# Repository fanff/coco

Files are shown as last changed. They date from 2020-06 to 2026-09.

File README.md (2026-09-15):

# Coco Walker

Software for **Coco**, a small **bipedal** walking robot. Coco has **two legs** and is driven by **four hobby servos**—a foot and a hip on each side (see `iv.py`). The repo runs on a **Raspberry Pi Zero W** with **pigpio** driving servo PWM on GPIO, and includes tools to design gaits, run them live, and control the robot from a browser.

Python dependencies are managed with **[uv](https://docs.astral.sh/uv/)** (`pyproject.toml` + `uv.lock`).

## Hardware

- **Computer**: Raspberry Pi Zero W
- **Biped**: two legs, four degrees of freedom total
- **4× MG90S servos** (2 per leg): foot + hip on left and right (mapping in `iv.py`)
- **Servo control**: [pigpio](https://abyz.me.uk/rpi/pigpio/) on four GPIO lines (`servoGpios` in `iv.py`); legacy PCA9685 ServoKit still supported via `servo_kit.py`
- **3D-printed parts**: OpenSCAD sources in `3dmodels/` (MG90S biped: left/right feet, left/right legs, base plate). See `3dmodels/README.md`.

### Power

**2S Li-ion** (two 18650 in series, **~7.4 V** nominal) through a **2S BMS**, then **two switching BECs** (common ground at the pack):

| Rail | Source | Notes |
|---|---|---|
| **Pi Zero W** | 5 V BEC, **~1 A** | Do not power the Pi from the servo BEC. |
| **Servo bus** | 5 V BEC, **3–4 A** | Servo **red/black** only from this rail—not from the Pi 5 V pin. |

Use BECs with an input range that covers **~6–8.4 V** (full 2S span). Add bulk capacitance on the servo 5 V rail near the connectors.

Servo **signal** wires go to the Pi GPIO pins in `iv.py`. PWM is **3.3 V**; most hobby servos accept it. Tie Pi GND and servo GND together once (star ground).

### GPIO wiring (default)

| Name | Index | GPIO (BCM) | Leg | Joint |
|---|---|---|---|---|
| feetL  | 0 | 17 | Left  | Foot |
| feetR  | 1 | 18 | Right | Foot |
| hipR | 2 | 27 | Right | Hip |
| hipL | 3 | 22 | Left  | Hip |

Change `servoGpios` in `iv.py` to match your harness. Home angles are in `iv=[...]`.

## How it works

```text
  Vue UI (frt/)          WebSocket (flsrv.py)         Pattern playback (readPulp.py)
        |                         |                              |
        +---- ws://host:8765 -----+---- cocoWalker.py ------------+
                                          |
                              servo_kit (pigpio / mock)
```

1. **`cocoWalker.py`** — Core motion layer. A background thread smoothly interpolates each servo toward target angles; `move()` and `setRot()` update targets without blocking the gait loop.
2. **`flsrv.py`** — Real-time walker. Sine-based forward gait on **port 8765**; accepts JSON (`freqfact`, `amplfact`) over WebSocket to adjust speed and amplitude. Uses pigpio when the daemon is running, otherwise a mock.
3. **`readPulp.py`** — Plays back keyframe curves from `file.json` (or UI exports), samples them with linear segments, and replays the motion a configurable number of times.
4. **`patterns/`** — Example gait JSON (`forward.json`, `rotateCW.json`, …) with time-series points per leg.
5. **`frt/`** — Vue 2 UI (`cocoui`) to draw leg curves per motor, export `file.json`, and connect over WebSocket. Set the host IP in the Vue sources to your board’s LAN address.

## Setup (uv)

Install [uv](https://docs.astral.sh/uv/getting-started/installation/), then from the repo root:

```bash
uv sync
```

This creates `.venv` and installs locked dependencies from `uv.lock`. Python **3.10+** is required (see `.python-version`).

Run scripts through uv so they use the project environment:

```bash
uv run python flsrv.py      # live WebSocket gait server
uv run python readPulp.py   # play file.json pattern (needs hardware)
uv run python test.py       # WebSocket smoke test
```

On the Pi, install and start the pigpio daemon, then use the same commands after `uv sync`:

```bash
sudo apt install pigpio python3-pigpio   # or build from pigpio repo
sudo pigpiod
sudo systemctl enable pigpiod            # optional: start on boot
```

Set `COCO_SERVO_BACKEND=mock` to force the software mock (laptops/CI). Use `servokit` for the legacy Adafruit HAT.

### Web UI

```bash
cd frt
npm install
npm run serve
```

## Repository layout

| Path | Description |
|---|---|
| `pyproject.toml` | Project metadata and Python dependencies |
| `uv.lock` | Locked dependency versions (commit this file) |
| `cocoWalker.py` | Servo controller with threaded interpolation |
| `iv.py` | Home angles, GPIO map, motor name map |
| `servo_kit.py` | pigpio / ServoKit / mock factory |
| `flsrv.py` | WebSocket gait server (port 8765) |
| `readPulp.py` | JSON pattern sampler and playback |
| `patterns/` | Saved gait curves |
| `frt/` | Vue control / pattern editor UI |
| `3dmodels/` | OpenSCAD sources for printable MG90S biped parts |
| `Untitled.ipynb` | Experiments and prototyping |

## Notes

- **Flask** packages are listed for experiments; the main control path uses **asyncio** and **websockets** in `flsrv.py`.
- **pigpio** needs `pigpiod` on the Pi. Off-device, `servo_kit.make_servo_kit()` falls back to a mock unless you set `COCO_SERVO_BACKEND`.
- The UI references a LAN IP (e.g. `192.168.1.58`); change it to match your robot host.
- `flsrv.py` accepts WebSocket messages as JSON with numeric fields such as `freqfact` and `amplfact` to tune the live gait.

## License

See [fanff/coco](https://github.com/fanff/coco) for authorship and licensing if applicable.

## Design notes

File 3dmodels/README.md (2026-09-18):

# 3D-printed parts — Coco biped

OpenSCAD sources for a small **biped** walker built around **four MG90S** micro servos (two per leg). Print these five parts:

| File | Qty | Role |
|---|-----|---|
| `foot_left.scad` | 1 | Left gnome sole (4 toes) + laid-down MG90S well (`feetL`) |
| `foot_right.scad` | 1 | Right gnome sole (4 toes) + laid-down MG90S well (`feetR`) |
| `leg_left.scad` | 1 | Left reverse-U shin: front peg at the 4 mm hole (rear/hip attach TBD) |
| `leg_right.scad` | 1 | Right reverse-U shin (mirror) |
| `base_plate.scad` | 1 | Deck where both **hip** servos plug in, plus Pi Zero W / BEC / battery straps |

Shared libraries (not printed on their own):

| File | Role |
|---|---|
| `mg90s.scad` | MG90S body, pocket cutter, round-horn pattern, `mg90s_orient_foot` |
| `coco.scad` | Robot dimensions and the part modules |
| `assembly.scad` | Preview of the full robot (F5) — **do not print**. RGB axes + two ankle anchors at the left foot. |
| `foot_preview.scad` | Left foot + motor + XYZ triad + anchors — **do not print** |
| `ankle_preview.scad` | Left reverse-U shin seated on the foot’s two anchors — **do not print** |

All dimensions are millimetres. The `.scad` files are the source of truth; export STL when you are ready to slice.

## Kinematics

Two degrees of freedom per leg, matching `iv.py` (`feetL` / `feetR` / `hipL` / `hipR`):

```text
                    +Z up
                    |
                    |      base plate (Pi Zero W, BECs, 2S pack)
           hipL ●---+---● hipR     shafts along ±Y (leg swings forward/back)
                |         |
            leg L      leg R       reverse-U shin (∩; verticals to the foot)
                |         |
             foot L     foot R     MG90S in the sole, laid down
                ●         ●        shafts along −X (backward; foot pitches)
                    |
                    +X forward
```

Each hip servo lives in a well on the base. The matching **leg** bolts onto the stock round horn. The shin is a simple **reverse U** (∩): a top bar at the hip and two vertical posts that drop to the foot’s shared **anchors** (`coco_foot_shaft_anchor` at the shaft / horn, `coco_foot_mirror_anchor` at the 4 mm front window). Orange and magenta pins in `foot_preview.scad` / `ankle_preview.scad` mark those points.

Each **foot** servo lives *in the sole* (the green part in `assembly.scad`), laid down so the 12.4 mm body width is vertical. That pose is the hip Y-shaft orientation turned **90° about +Z**, then **180° about the shaft (world X)**: the output shaft still points **backward** (−X), the 23 mm body occupies +X (toward the toes), and the round horn sticks out the heel. The 4 mm front window stays on that same shaft axis, opposite the horn. The well is sliced by a horizontal plane at the **motor top**, so there is no roof or wall above the servo — it slides in from above. A **notch from the top** of the **inboard** wall lets the servo lead pass through as the motor drops in.

The ground plate is a compact **gnome foot**: four overlapping flattened-sphere toes in front (the balls collide so they are not split fingers; the outboard toe is the smallest), a sole that **runs from the motor housing out to the toes**, and a **short heel** so the shin flange still clears at the back. Around the well the pad still **hugs the socket** (walls do not flare). The front wall of the well — opposite the shaft / heel horn — has a round **through-hole** on the shaft axis (`front_hole_d`, default 4 mm). Those two holes are the reverse-U shin’s attach points: a round-horn flange on the shaft, and a peg into the 4 mm window. Well walls may rise in Z around the motor and a bit toward the front. Commanding `feetL` / `feetR` pitches the foot about the shaft. Left and right parts are mirrors.

Default layout in `coco.scad` (edit these to retune stance):

| Parameter | Default | Meaning |
|---|---|---|
| `hip_span` | 72 mm | Hip shaft to hip shaft (Y) |
| `leg_len` | 56 mm | Hip shaft to foot-servo shaft (Z) |
| `ankle_h` | 14.2 mm | Foot-servo shaft above the ground (`BODY_W/2 + clearance + wall + sole_t`) |
| `toe_reach` | 43 mm | Forward-most toe-ball centre, from the foot-servo shaft |
| `coco_toe_d` | 16, 15, 14, 10 mm | Toe-ball diameters (inboard → outboard) |
| `front_hole_d` | 4 mm | Round hole in the front socket wall (shaft axis); U peg target |
| `hug_inset` | 2 mm | How far the well pad tucks under the socket walls |
| `heel_lip` | 2 mm | Sole behind the shaft (kept short for the shin) |
| `leg_beam_t` | 6 mm | Reverse-U beam thickness |
| `leg_beam_d` | 20 mm | Reverse-U beam depth along +Y (outboard) |
| `leg_y0` | 2 mm | Inboard face of the beams (slightly outboard of horn plane) |
| `leg_top_z` | −leg_len+10.5 | Underside of the top bar (just above the foot motor) |
| `clearance` | 0.40 mm | MG90S pocket clearance |

## Bill of materials (hardware)

- 4× **MG90S** (or SG90-sized clones — pockets have 0.4 mm clearance)
- 4× stock **round horns** and horn screws
- 8× M2×8 mm screws for servo mounting tabs (optional; zip-ties also work)
- Raspberry Pi Zero W (M2.5×8 mm into the four standoffs)
- Two 5 V BECs and a 2S 18650 pack (zip-tie slots under the deck)
- 4× hobby-servo 3-pin leads to the GPIO map in `iv.py`

## Export STL

Install [OpenSCAD](https://openscad.org/) 2021.01 or newer, then from this folder:

```bash
mkdir -p stl
openscad -o stl/foot_left.stl   foot_left.scad
openscad -o stl/foot_right.stl  foot_right.scad
openscad -o stl/leg_left.stl    leg_left.scad
openscad -o stl/leg_right.stl   leg_right.scad
openscad -o stl/base_plate.stl  base_plate.scad
```

Or: `make stl`. Open `assembly.scad`, `foot_preview.scad`, or `ankle_preview.scad` and press **F5**. They draw an RGB triad at the left foot-servo shaft: **+X** red (forward / toes), **+Y** green (left / outboard), **+Z** blue (up), **−X** maroon (shaft / heel). Orange and magenta pins mark the two U-leg anchors (shaft horn and 4 mm front hole). The right foot is a Y-mirror of the left solid.

## Print settings

| | |
|--|--|
| Material | PLA or PETG |
| Layer height | 0.20 mm |
| Infill | 20–30 %, gyroid or grid |
| Perimeters | 3 |
| Supports | None for feet and the reverse-U legs. Light supports only if a hip-well overhang sags on the base plate. |

Suggested bed orientation (already applied in the printable files):

- **Feet** — sole on the bed. Well is open at the motor top (no roof); no supports.
- **Legs** — reverse-U flat on the bed, outboard face up (`coco_leg_print`). No supports.
- **Base plate** — floor on the bed, wells facing up

Each foot and each leg exports as **one printable shell** (no floating chips). The foot servo **slides** into the sole from above (the well is cut off at the motor top); a zip-tie through the well retains it if you skip the tab screws. The shin’s front post peg goes through the 4 mm window; the rear post sits at the shaft plane (round horn boss TBD).

## Assembly

1. Drop the two **hip** MG90S units into the base wells, cables toward the Pi. Tabs sit in the side slots; optional M2 screws through the tab holes. Shafts point **outboard**.
2. Fit a round horn on each hip. Bolt `leg_left` / `leg_right` onto those horns (horn screw through the printed flange).
3. Slide an MG90S into each **foot** well from above, body laid down, shaft pointing **backward** (out the heel). The well has no roof — it is cut off at the motor top. Drop the servo lead through the open notch in the **inboard** wall (toward the other foot). Optional M2 screws through the tab holes; otherwise zip-tie through the well.
4. Fit a round horn on each foot servo. Seat the matching shin so the front peg slides into the 4 mm hole (rear horn attach TBD).
5. Mount the Pi Zero W on the four standoffs (USB/HDMI toward the rear). Strap the 2S pack under the deck. Sit the BECs on the raised pads. Route foot-servo wires up between the reverse-U posts and through the rim holes next to each hip.
6. Home angles and GPIO are still those in `iv.py`; power the servo rail from the 3–4 A BEC, not from the Pi 5 V pin.

Tune `clearance` in `coco.scad` if a clone body is tight or sloppy. Tune `hip_span`, `leg_len`, `ankle_h`, `toe_reach`, `coco_toe_*`, `front_hole_d`, `hug_inset`, `leg_beam_t`, and `leg_beam_d` there if you change stance, footprint, hole size, or shin section. The reverse-U’s fore–aft span follows `coco_foot_mirror_hole_x()`.

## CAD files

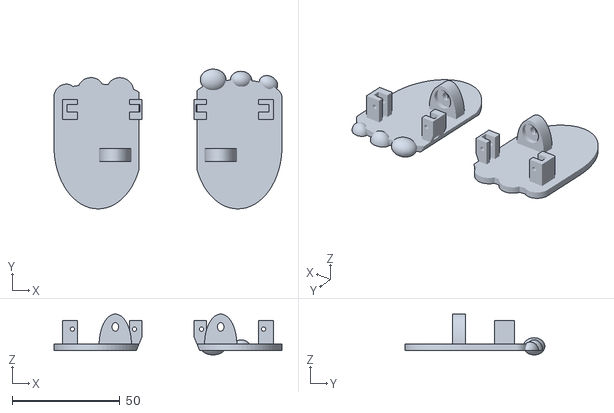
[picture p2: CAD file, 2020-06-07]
3dmodels/feet.stl
106.0 x 65.0 x 19.0

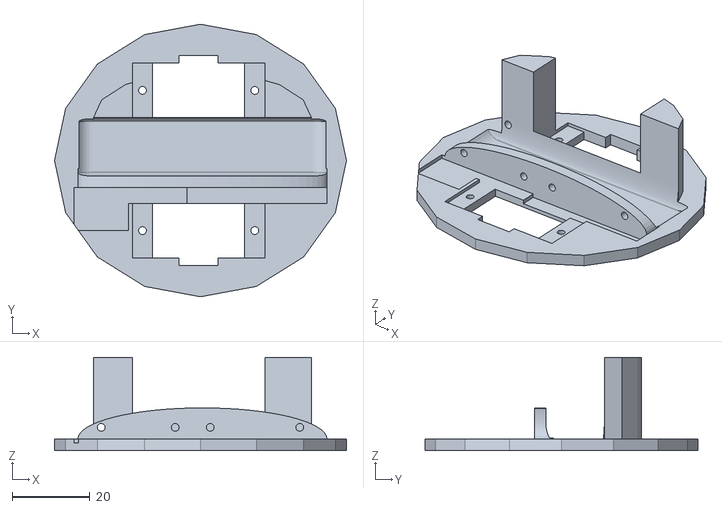
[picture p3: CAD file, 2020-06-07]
3dmodels/body.stl
75.0 x 70.0 x 24.0

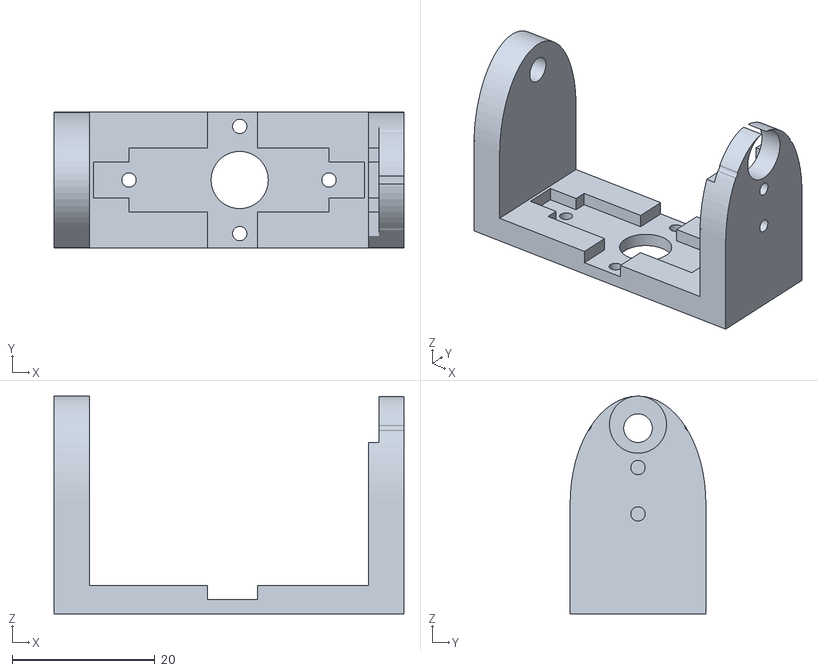
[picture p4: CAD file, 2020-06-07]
3dmodels/leg.stl
49.0 x 19.0 x 30.5

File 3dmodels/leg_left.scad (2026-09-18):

// Coco — left leg (reverse-U shin: foot shaft + 4 mm peg at the bottom; hip attach TBD).
// Print flat on the bed, outboard face up.
include <coco.scad>
coco_leg_print(side = 1);

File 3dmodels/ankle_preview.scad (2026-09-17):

// Coco — left reverse-U shin on the left foot, at the two anchors (not printable).
// Rear orange pin = shaft / horn. Front magenta pin = 4 mm mirror hole.
include <coco.scad>

$vpr = [68, 0, 35];
$vpt = [14, 0, 18];
$vpd = 260;

color("YellowGreen")
    coco_foot(side = 1);

color("SteelBlue")
    mg90s_orient_foot()
        mg90s_dummy();

color("Tomato")
    translate([0, 0, leg_len])
        coco_leg(side = 1);

coco_axes(len = 22);
coco_foot_anchor_markers();

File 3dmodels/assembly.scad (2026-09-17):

// Coco — assembled preview (not a printable part).
// Opens in OpenSCAD F5 to check fit: 4× MG90S, two reverse-U legs, two feet, deck.
// RGB axes sit on the left foot shaft (+X forward, +Y left, +Z up).
// Default camera looks in from the rear-left so the in-foot motors are visible
// (laid down in the green soles, shafts pointing backward).

include <coco.scad>

$vpr = [68, 0, 148];
$vpt = [hip_x - 8, 0, coco_hip_z_world() * 0.28];
$vpd = 290;

module coco_hip_servo(side) {
    translate([hip_x, coco_hip_y(side), coco_hip_z_world()])
        mg90s_orient_shaft_y(side)
            mg90s_dummy();
}

module coco_foot_servo(side) {
    translate([hip_x, coco_hip_y(side), ankle_h])
        mirror([0, side < 0 ? 1 : 0, 0])
            mg90s_orient_foot()
                mg90s_dummy();
}

module coco_assembly(exploded = 0) {
    base_z = coco_hip_z_world() - hip_z;
    e = exploded;

    translate([0, 0, base_z + e * 25])
        color("SlateGray")
            coco_base_plate();

    for (s = [1, -1]) {
        coco_hip_servo(s);

        translate([hip_x, coco_hip_y(s), coco_hip_z_world() + e * 18])
            color(s > 0 ? "Tomato" : "Orange")
                coco_leg(s);

        coco_foot_servo(s);

        translate([hip_x, coco_hip_y(s), ankle_h - e * 16])
            color(s > 0 ? "YellowGreen" : "OliveDrab")
                coco_foot(s);
    }

    // World / left-foot frame at the left ankle shaft (coco.scad origin).
    // +X forward, +Y left, +Z up, −X shaft/heel. Right foot is a Y-mirror.
    translate([hip_x, coco_hip_y(1), ankle_h])
        coco_axes(len = 24);
    translate([hip_x, coco_hip_y(1), ankle_h])
        coco_foot_anchor_markers();
}

exploded = 0; // set to 1 for an exploded preview
coco_assembly(exploded = exploded);

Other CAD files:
3dmodels/leg_right.scad
3dmodels/base_plate.scad
3dmodels/coco.scad
3dmodels/foot_left.scad
3dmodels/foot_preview.scad
3dmodels/foot_right.scad
3dmodels/mg90s.scad

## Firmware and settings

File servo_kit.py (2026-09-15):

"""Servo backends for Coco: pigpio (GPIO), optional legacy ServoKit, or mock."""

import logging
import os
import socket

# BCM pins: feetL, feetR, hipR, hipL (same order as iv channel indices)
from iv import servoGpios

PULSE_MIN_US = 500
PULSE_MAX_US = 2500


def angle_to_pulse_us(angle):
    angle = max(0.0, min(180.0, float(angle)))
    span = PULSE_MAX_US - PULSE_MIN_US
    return int(PULSE_MIN_US + (angle / 180.0) * span)


class ServoMockup:
    def __init__(self, index):
        self.index = index

    @property
    def angle(self):
        return None

    @angle.setter
    def angle(self, value):
        logging.getLogger("servo.mock").info("servo[%s].angle = %s", self.index, value)


class SKitMockup:
    def __init__(self, n_motors=4):
        self.servo = [ServoMockup(i) for i in range(n_motors)]

    def close(self):
        pass


class _ServoAngle:
    __slots__ = ("_set_angle",)

    def __init__(self, set_angle):
        self._set_angle = set_angle

    @property
    def angle(self):
        return None

    @angle.setter
    def angle(self, value):
        self._set_angle(value)


class PigpioKit:
    def __init__(self, pi, gpios):
        self._pi = pi
        self._gpios = list(gpios)
        self.servo = [
            _ServoAngle(lambda a, g=gpio: self._write(g, a))
            for gpio in self._gpios
        ]
        log = logging.getLogger("servo.pigpio")
        for gpio in self._gpios:
            self._pi.set_mode(gpio, self._pi.OUTPUT)
            log.info("servo on GPIO %s", gpio)

    def _write(self, gpio, angle):
        pulse = angle_to_pulse_us(angle)
        self._pi.set_servo_pulsewidth(gpio, pulse)

    def close(self):
        for gpio in self._gpios:
            self._pi.set_servo_pulsewidth(gpio, 0)
        self._pi.stop()


def _pigpiod_running(host=None, port=None):
    host = host or os.environ.get("PIGPIO_ADDR", "localhost")
    port = int(port or os.environ.get("PIGPIO_PORT", "8888"))
    try:
        with socket.create_connection((host, port), timeout=0.2):
            return True
    except OSError:
        return False


def _make_pigpio_kit(log):
    if not _pigpiod_running():
        raise RuntimeError("pigpio daemon not running (start with: sudo pigpiod)")

    import pigpio

    pi = pigpio.pi()
    if not pi.connected:
        pi.stop()
        raise RuntimeError("pigpio daemon not running (start with: sudo pigpiod)")
    log.info("using pigpio on GPIOs %s", servoGpios)
    return PigpioKit(pi, servoGpios)


def _make_servokit(log):
    from adafruit_servokit import ServoKit

    kit = ServoKit(channels=16)
    log.info("using Adafruit ServoKit (legacy PCA9685)")
    return kit


def make_servo_kit(logger=None):
    """
    Return a kit object with .servo[i].angle for i in 0..3.
    Backend order: COCO_SERVO_BACKEND env, else pigpio, ServoKit, mock.
    """
    log = logger or logging.getLogger("servo")
    backend = os.environ.get("COCO_SERVO_BACKEND", "").strip().lower()

    if backend == "mock":
        log.warning("COCO_SERVO_BACKEND=mock")
        return SKitMockup()

    if backend == "servokit":
        return _make_servokit(log)

    if backend == "pigpio":
        return _make_pigpio_kit(log)

    for name, factory in (
        ("pigpio", _make_pigpio_kit),
        ("servokit", _make_servokit),
    ):
        try:
            return factory(log)
        except Exception as e:
            log.warning("%s unavailable: %s", name, e)

    log.warning("using servo mock (no hardware backend)")
    return SKitMockup()

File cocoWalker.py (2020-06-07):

import threading
import time
import logging



class CocoWalker():
    def __init__(self,mkit,iv):
        self.mkit = mkit
        self.iv=iv
        self.state = [[iv[i], iv[i], 10,0] for i in range(4)]
        self.locks = [threading.Lock() for i in range(4)]
        self.run=False 

        self.log = logging.getLogger("cocow")
        self.dataHandler = logging.getLogger("cocodata")

    def setAtIv(self):
        for k,v in enumerate(self.iv):
            self.setAngle(k,v)

    def setAngle(self,mot,angle):
        self.mkit.servo[mot].angle=angle
        self.state[mot][:2] = [angle,angle]
    
    def setRot(self,mot,rot):
        self.mkit.servo[mot].angle = self.iv[mot] + rot

    def startThread(self):

        
        for mot in range(4):
            self.state[mot][-1] = time.time()


        self.run=True 
        self.thread = threading.Thread(target=self.th_loop)
        self.thread.start()

    def th_loop(self):

        
        while self.run:
            now = time.time()
            # for each motor
            for mot,(pos,dest,speed,lastup) in enumerate(self.state):
                self.locks[mot].acquire() 
                self.log.debug("got %s, state %s",mot,(pos,dest,speed,lastup)) 
                # recalculate next step
                now=time.time()
                dur = (now-lastup)
                steplen = min(dur*speed,abs(dest-pos))

                # nextpos
                nextpos = pos+steplen if dest>pos else pos-steplen
                nextpos = int(nextpos) 
                nextposcapped=min(max(nextpos,0),180)#nextpos
                # set 
                if nextpos != pos:

                    self.log.debug("next pos %s,nextpos : %s, capped: %s ,%s"%(mot,nextpos,nextposcapped,int(steplen))) 

                    
                    self.mkit.servo[mot].angle=nextposcapped
                    self.dataHandler.info("next pos %s,nextpos : %s, capped: %s ,%s"%(mot,nextpos,nextposcapped,int(steplen))) 
                # keep state
                self.state[mot][0] = nextposcapped
                self.state[mot][3] = now
    
                self.locks[mot].release() 
                self.log.debug("left %s"%mot) 
                
            time.sleep(.02)

    def stopThread(self):
        self.run=False

    def move(self,mot,rangle,speed=None):
        self.log.debug('move %s',mot)
        self.locks[mot].acquire() 
        if speed :
           self.state[mot][2]= speed
        
        # take lock
        self.state[mot][1] = self.iv[mot]+rangle
        self.locks[mot].release() 
        self.log.debug('done move %s',mot)


class DataHandler(logging.Handler):
    def __init__(self):
        logging.Handler.__init__(self)
        self.data=[]
    def handle(self,logobject):
        self.data.append([float(_) for _ in logobject.msg.split(",")])
    def dump(self):
        print(self.data)
        
        
def setSymFeet(kit,angle,interSleep=0,finalSleep=0):
    for serid,angl in zip(range(2),[90+angle,90-angle]):
        kit.servo[serid].angle = angl
        if interSleep:
            time.sleep(interSleep)

    if finalSleep:
        time.sleep(finalSleep)

def setAll(kit,angle,interSleep=0,finalSleep=0):
    for serid in range(4):
        kit.servo[serid].angle = angle

        if interSleep:
            time.sleep(interSleep)
    if finalSleep:
        time.sleep(finalSleep)

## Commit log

2020-06-07 adding 3D models
    [body.stl, feet.stl, leg.stl]
2026-05-22 build: migrate Python dependencies to uv
    Replace requirements.txt with pyproject.toml and a committed uv.lock.
    Document uv sync/run workflow in README and pin Python 3.12 via
    .python-version. Mark project as a non-packaged application (tool.uv
    package = false) for the flat script layout at repo root.
2026-05-23 docs: describe Coco as bipedal with four servos
    Correct README and pyproject description: two-legged biped driven by
    four servos (foot and hip per side), not a quadruped.
2026-05-25 docs: specify Pi Zero W and power rails in README and AGENTS.md
2026-09-15 Add pigpio servo backend and document 2S dual-BEC power (#32)
    - Introduce servo_kit.make_servo_kit() with pigpio GPIO PWM, legacy
    ServoKit fallback, and mock for off-device use
    - Map four servos to BCM pins in iv.servoGpios (default 17,18,27,22)
    - Wire flsrv.py and readPulp.py through the shared factory
    - Update README and AGENTS.md for 2S 18650+BMS and dual BEC power
2026-09-15 Add OpenSCAD MG90S biped parts under 3dmodels/
    Introduce a dedicated printable-parts folder with left/right feet,
    left/right legs, and a base plate for hip servos plus Pi Zero W
    electronics. Shared MG90S library and assembly preview included.
    [assembly.scad, base_plate.scad, coco.scad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]
2026-09-16 Redesign MG90S legs and feet as single-shell printable parts
    Fuse the hip flange, 16 mm shin pipe, and ankle cage into one solid, and
    fuse the foot's ankle column into the sole so STL export is a single
    shell. Open the pipe cable duct at both ends, stamp L/R on the toes, and
    add inset tread that stays inside the sole outline.
    [assembly.scad, coco.scad, foot_left.scad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]
2026-09-16 Remake the shin as an outboard-opening U-channel
    Replace the pipe-and-box leg with a U-channel that opens toward the
    side of the robot so the ankle MG90S sits in the U and is visible in
    the assembly drawing. Print with the inboard web on the bed.
    [assembly.scad, coco.scad, leg_left.scad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]
2026-09-16 Put the foot MG90S in the sole, laid down, shaft backward
    Rotate the feet servos 90° about +Z from the hip Y-shaft pose so each
    motor lives in the green sole (12.4 mm width vertical, shaft −X). The
    U-channel shin now ends in a horn flange at the heel instead of holding
    the ankle servo.
    [assembly.scad, coco.scad, foot_left.scad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]
2026-09-16 Slice the foot well at the motor top so the servo slides in
    A horizontal plane at the laid-down MG90S top face removes all sole
    plastic above that height, leaving an open tray instead of a roofed
    cage. The 3dmodels README still describes the in-sole foot layout.
    [coco.scad, foot_left.scad, foot_right.scad]
2026-09-16 Add an open-top wire notch on each foot well
    Cut a slot from the motor-top plane down through the outboard wall at
    the MG90S cable exit so the servo lead drops in with the motor.
    [coco.scad]
2026-09-16 Give the foot sole a compact gnome four-toe outline
    The ground plate hugs the motor in X/Y with only a little margin, stays
    short at the heel so the shin flange still clears, and grows four gnome
    toes in front. Well walls still occupy Z around the motor.
    [coco.scad]
2026-09-16 Merge gnome toes into overlapping flattened spheres
    Replace the split flat finger-toes with four colliding balls, squashed
    in Z, so they read as one blob instead of separate digits.
    [coco.scad]
2026-09-17 Narrow the gnome soles, raise the toe balls, drop L/R stamps
    Pull the pad and overlapping toe spheres in on Y, increase toe_z_scale
    so the balls sit a bit higher, and remove the sole letter stamps.
    [coco.scad, foot_left.scad, foot_right.scad]
2026-09-17 Hug the sole to the motor well and add a front socket hole
    Tuck the ground pad under the well walls and cut a round window in the
    front of the socket, on the shaft axis, opposite the heel horn.
    [coco.scad]
2026-09-17 Tuck the sole under the well and punch a front-wall hole
    Inset the ground pad from the motor-well outline so the exterior walls
    taper into the socket, and cut a round window in the front wall on the
    shaft axis without reaching the toes.
    [coco.scad]
2026-09-17 Stretch the sole to the toes and shrink the front socket hole
    Hull the ground plate from the well pad out to the gnome balls so it is
    no longer a tiny island under the motor. The outboard toe is 10 mm, and
    the front-wall hole is a 4 mm `front_hole_d` parameter.
    [coco.scad]
2026-09-17 Keep the 4 mm front hole manifold with the wire notch
    Sink the toe balls into the sole plate and stop the wire-notch cutter
    short of the shaft axis so the 4 mm window is a clean through-hole.
    [coco.scad]
2026-09-17 Show XYZ axes on the left foot in the OpenSCAD preview
    Draw a robot-frame triad at the foot-servo shaft (+X toes, +Y left,
    +Z up, −X heel) in assembly.scad and a dedicated foot_preview.scad so
    later sole edits have a visible origin.
    [assembly.scad, coco.scad, foot_preview.scad]
2026-09-17 Note the left-foot RGB axes in the assembly preview header
    [assembly.scad]
2026-09-17 Thicken the preview axes and park the labels off the well
    [coco.scad]
2026-09-17 Document the top-down camera for the foot axis preview
    [foot_preview.scad]
2026-09-17 Flip the foot MG90S 180° about the shaft axis
    Spin the in-sole servo around world X so the cable sits inboard. The
    heel shaft opening and the 4 mm front window stay on that axis,
    opposite each other; the well pad and toes follow the new body Y.
    [coco.scad, mg90s.scad]
2026-09-17 Attach the U-shin at the shaft and the 4 mm mirror hole
    Name those two points as shared anchors and span the U arms between
    them: round-horn flange at the heel, peg through the front window.
    [ankle_preview.scad, assembly.scad, coco.scad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]
2026-09-17 Simplify the shin into a reverse-U on the two foot anchors
    Replace the sideways U-channel with a simple ∩ frame: a top bar at the
    hip and two vertical posts that drop to the shaft horn and the 4 mm
    front peg. Update print orientation and docs to match.
    [ankle_preview.scad, assembly.scad, coco.scad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]
2026-09-17 Lower the reverse-U over the foot and extend it outboard (+Y)
    Drop the top bar to just above the foot motor and grow the beams along
    +Y so the shin sits lower on Z and reaches further outboard, with a rear
    stem up to the hip flange.
    [coco.scad]
2026-09-17 Fix leg print bed offset for the foot horn disk
    The ankle flange spans ±foot_boss_d/2 in Y; lift the print solid so that
    disk sits on the bed instead of clipping below Z=0.
    [coco.scad]
2026-09-18 Raise the reverse-U 0.5 mm and drop the hip stem for now
    Lift the top bar by half a millimetre and remove the raised rear post
    and round hip flange on −X until the hip attach is redesigned.
    [coco.scad, leg_left.scad, leg_right.scad]
2026-09-18 Note hip attach is TBD on the reverse-U leg parts
2026-09-18 Remove the rear round horn flange from the reverse-U leg
    Drop the −X foot horn boss and its cuts so the aft post is a plain
    beam; keep the front peg. Fix the print bed offset for the peg boss.
    [coco.scad]
